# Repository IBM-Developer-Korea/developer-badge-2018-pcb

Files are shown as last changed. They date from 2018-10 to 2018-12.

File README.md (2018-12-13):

# Badge PCB

This repository contains schematic, PCB and BoM for Developer Day 2018 Badge

[KiCAD 5](http://kicad-pcb.org/download/) is used to design.

## 3D modeling

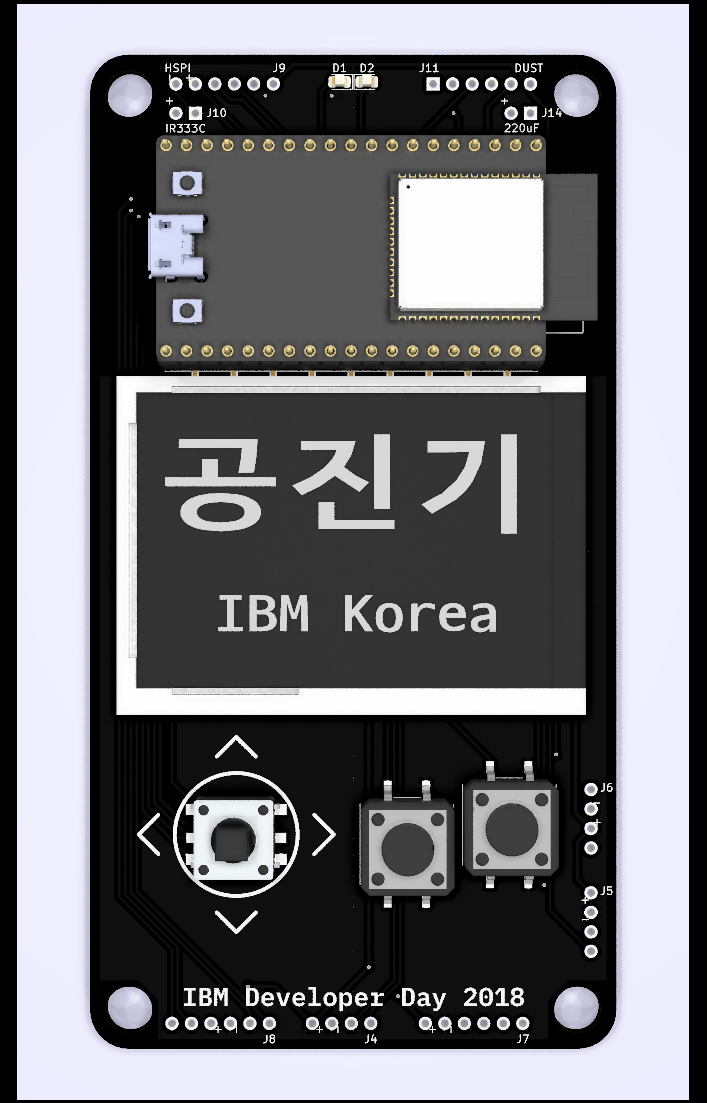
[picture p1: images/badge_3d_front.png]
Front

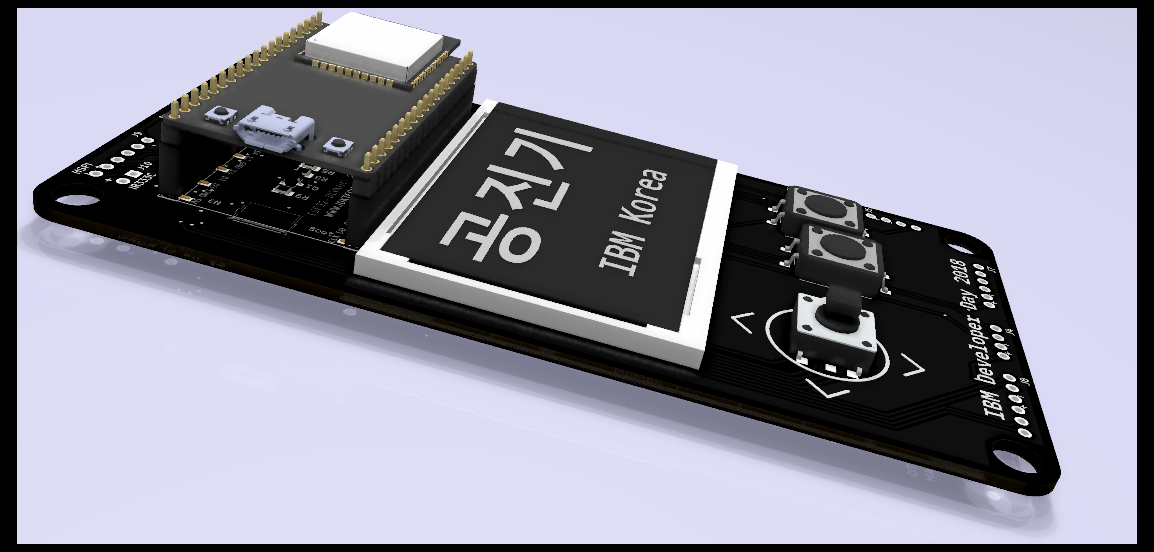
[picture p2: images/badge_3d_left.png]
Left

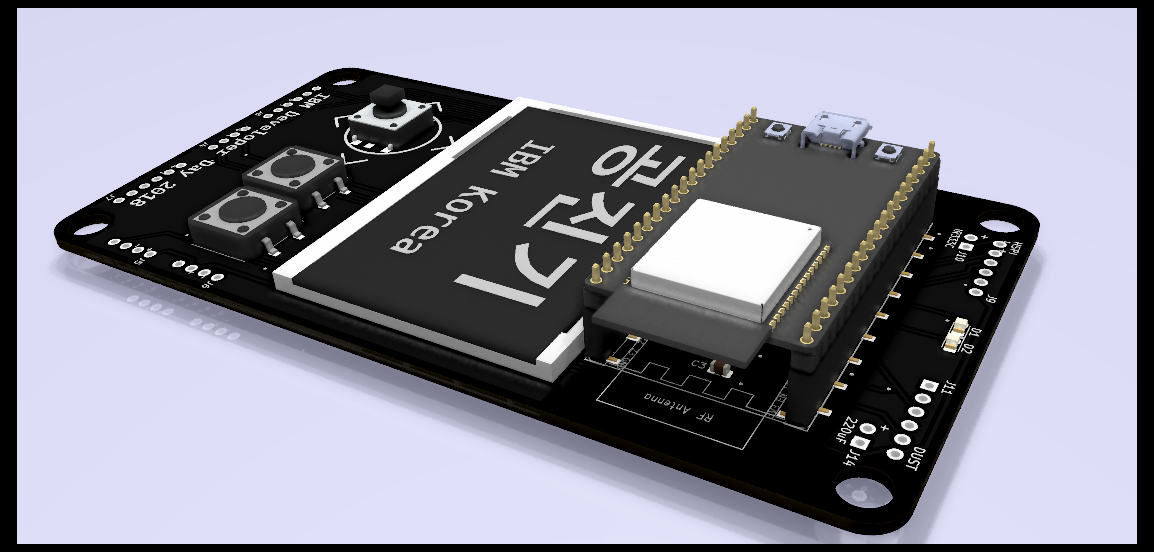
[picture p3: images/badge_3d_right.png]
Right

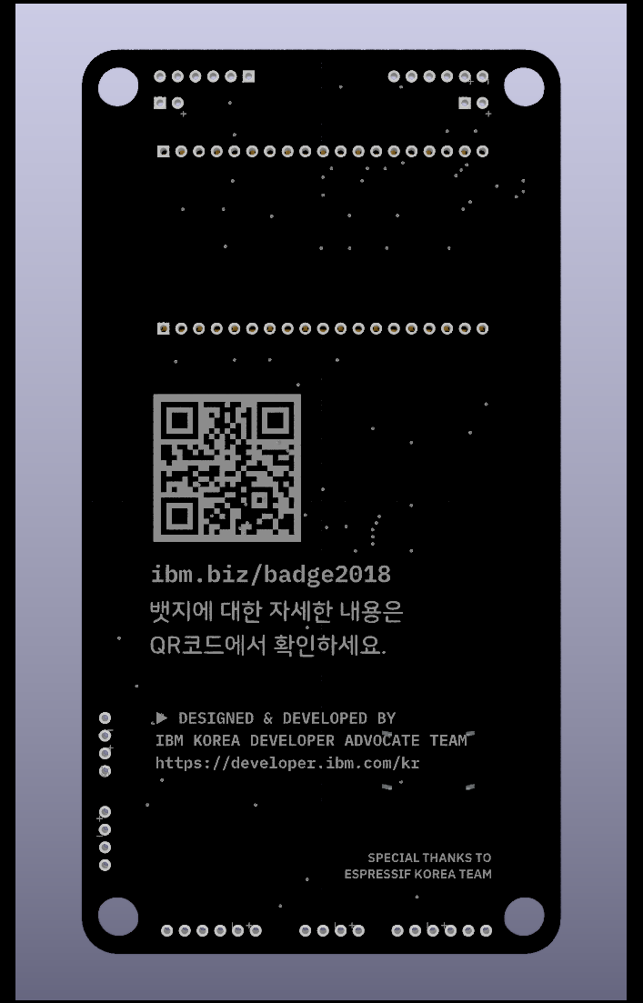
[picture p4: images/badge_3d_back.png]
Back


## Errata

* v1.0: in J9(HSPI), silk for +/- should be swapped. Correct pin is +(VCC), -(GND), GPIO14, GPIO12, GPIO13, GPIO15.

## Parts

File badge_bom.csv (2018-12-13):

Item | Qty | Reference(s) | Value | LibPart | Footprint | Datasheet | Field4 | Field5 | Field6 | Field7 | Field8
1 | 2 | C2, C8 | 2012/0.1uF | C_Small | C_0805
2 | 1 | C3 | 2012/100nF | C_Small | C_0805
3 | 1 | D1 | 2012/BLUE | LED_Small | LED_0805
4 | 1 | D2 | 2012/YELLOW | LED_Small | LED_0805
5 | 1 | DS1 | 18PIN LCD | LCD_SPI_18P | FFC-1x18-1MP_P0.80mm
6 | 1 | DS2 | 40PIN LCD | HT024SQV010NH | 05002HR-40C_1x40-1MP_P0.50mm_Horizontal
7 | 4 | H1, H2, H5, H6 | MountingHole | MountingHole | LanyardHole_6mm
8 | 1 | J1 | DevKitC_L | Conn_01x19_Female | PinSocket_1x19_P2.54mm_Vertical_BackOnly
9 | 1 | J2 | DevKitC_R | Conn_01x19_Female | PinSocket_1x19_P2.54mm_Vertical_BackOnly
10 | 1 | J4 | ADC_3 | Conn_01x04_Female | PinSocket_1x04_P2.54mm_Vertical
11 | 1 | J5 | ADC_2 | Conn_01x04_Female | PinSocket_1x04_P2.54mm_Vertical
12 | 1 | J6 | ADC_1 | Conn_01x04_Female | PinSocket_1x04_P2.54mm_Vertical
13 | 1 | J7 | DAC_1 | Conn_01x06_Female | PinSocket_1x06_P2.54mm_Vertical
14 | 1 | J8 | DAC_2 | Conn_01x06_Female | PinSocket_1x06_P2.54mm_Vertical
15 | 1 | J9 | HSPI | Conn_01x06_Female | PinSocket_1x06_P2.54mm_Vertical
16 | 1 | J10 | IR333C | Conn_01x02_Female | PinSocket_1x02_P2.54mm_Vertical
17 | 1 | J11 | DUST | Conn_01x06_Female | PinSocket_1x06_P2.54mm_Vertical
18 | 1 | J12 | DevKitC_L_SMD | Conn_01x19_Female | PinSocket_1x19_P2.54mm_Vertical_SMD_Pin1Right
19 | 1 | J13 | DevKitC_R_SMD | Conn_01x19_Female | PinSocket_1x19_P2.54mm_Vertical_SMD_Pin1Left
20 | 1 | J14 | 220uF | Conn_01x02_Female | PinSocket_1x02_P2.54mm_Vertical
21 | 1 | LCD1 | 2.4" LCD 18PIN | Housing | 2.4INCH_TFT_LCD_18P_0.80mm_FOLD
22 | 1 | LCD2 | 2.4" LCD 40PIN | Housing | 2.4INCH_TFT_LCD_40P_0.50mm_FOLD
23 | 1 | Q1 | SOT23/2N7002 | 2N7002 | SOT-23 | https://www.fairchildsemi.com/datasheets/2N/2N7002.pdf
24 | 3 | R4, R8, R9 | 2012/4.7R | R_Small | R_0805_2012Metric
25 | 2 | R5, R6 | 2012/1K | R_Small | R_0805_2012Metric
26 | 1 | R7 | 2012/220R | R_Small | R_0805_2012Metric
27 | 1 | SW3 | ITS-1103S | SW_Push | ITS-1103S |  | ILOSAM
28 | 1 | SW6 | ITS-1103S | SW_Push | ITS-1103S |  | ILOSAM
29 | 1 | SW7 | ITS_1500S_B | SW_5WAY | ITS-1500S-B |  | ILOSAM
30 | 1 | U1 | ESP32-DEVKITC-32D | ESP32-DEVKITC-32D | MODULE_ESP32-DEVKITC-32D-SILKONLY-SIMPLE | None | Espressif Systems | ESP32-DEVKITC-32D | None | Eval Board For Esp-Wroom-32 | Unavailable

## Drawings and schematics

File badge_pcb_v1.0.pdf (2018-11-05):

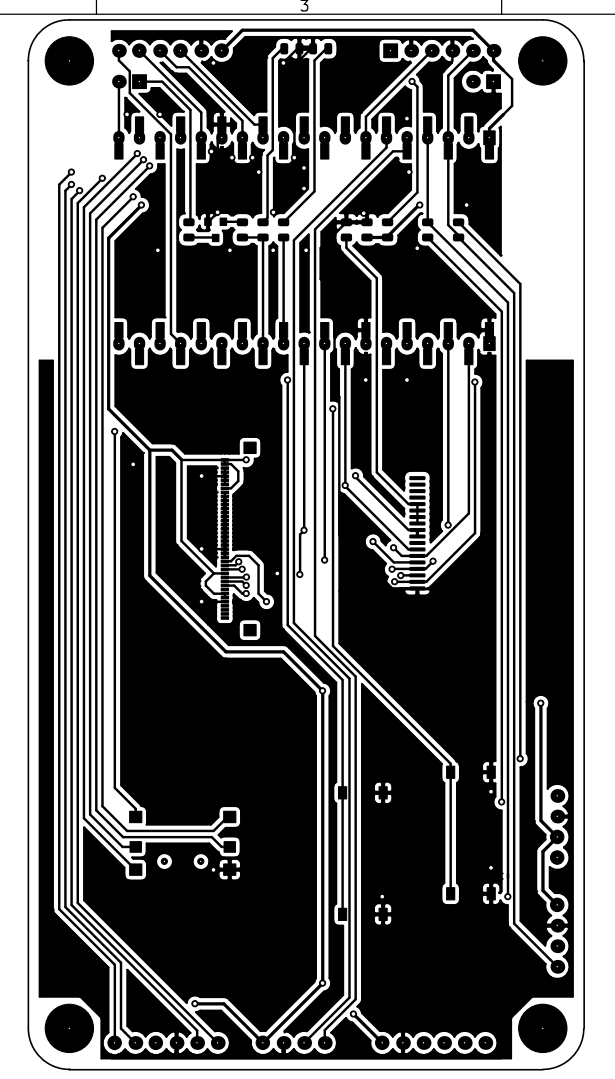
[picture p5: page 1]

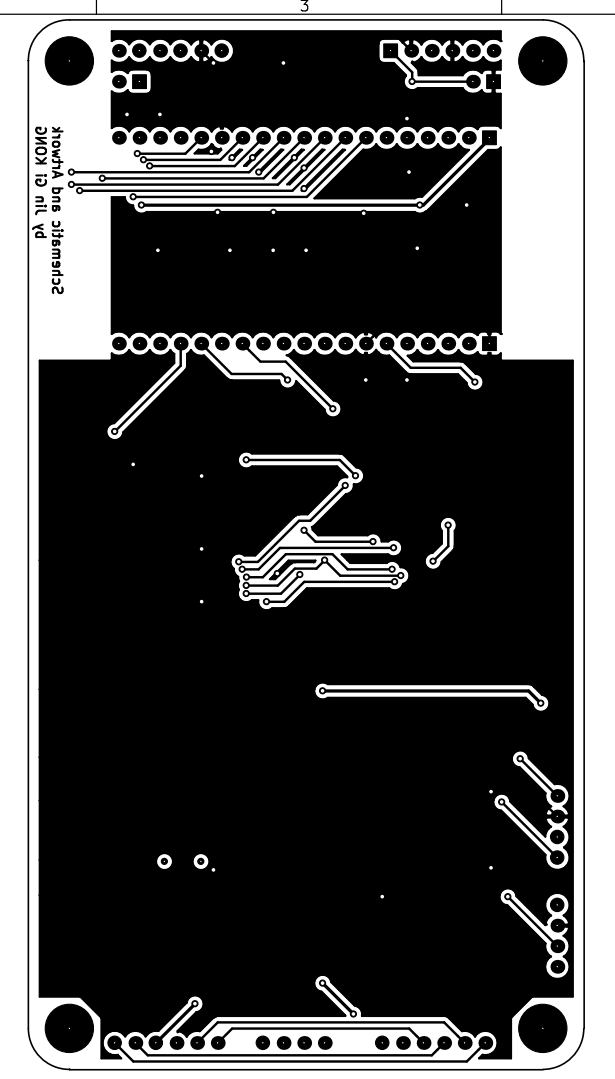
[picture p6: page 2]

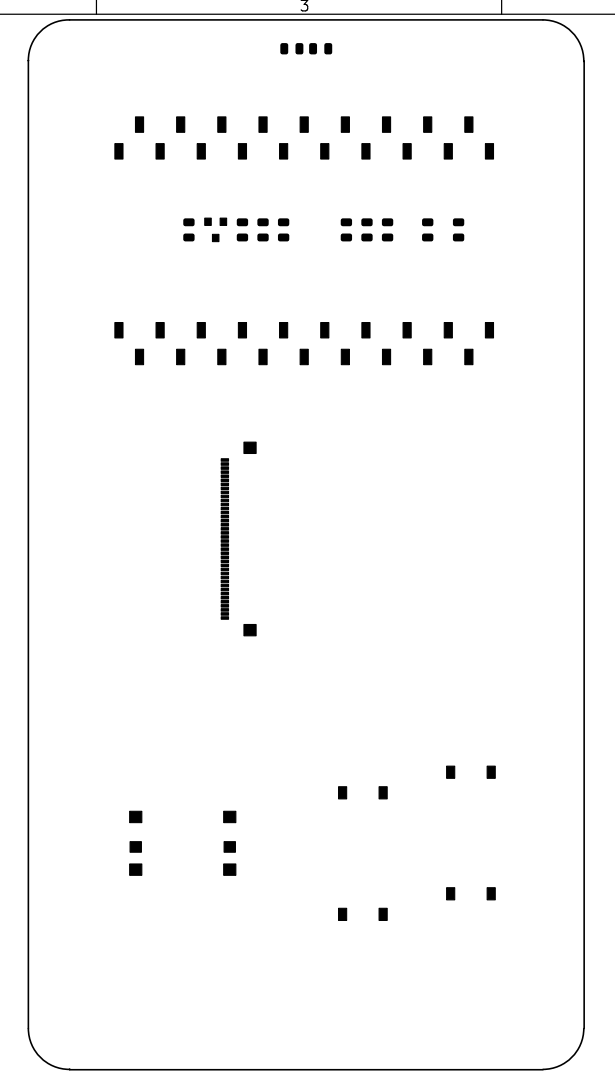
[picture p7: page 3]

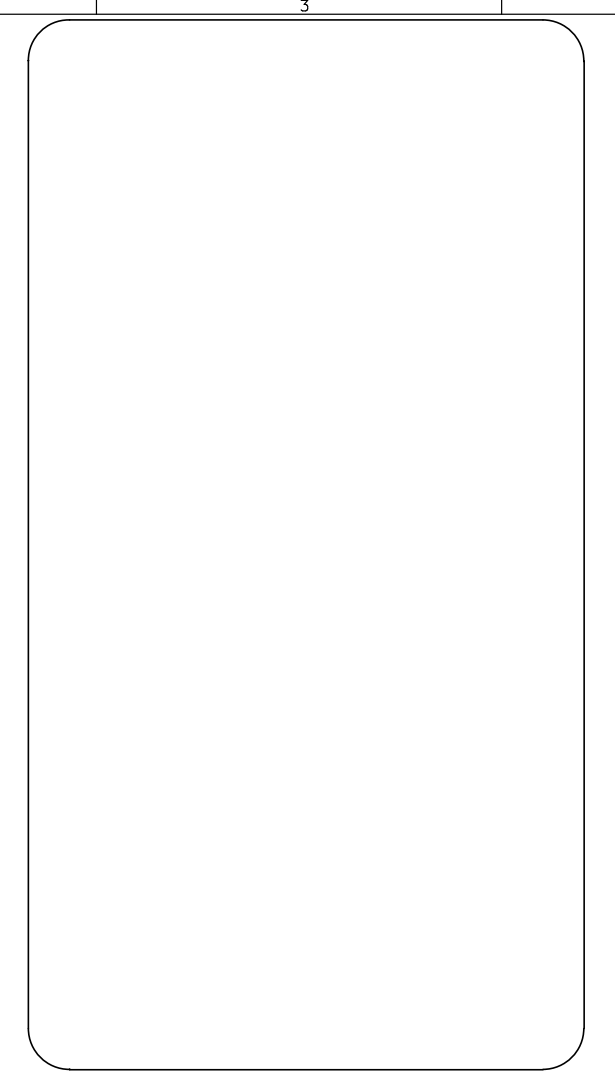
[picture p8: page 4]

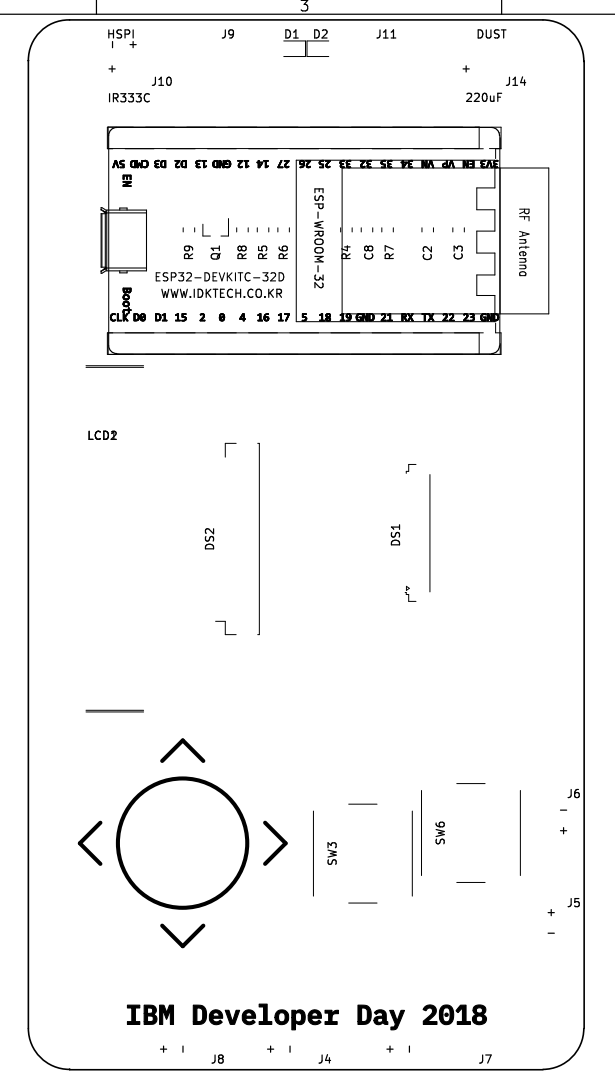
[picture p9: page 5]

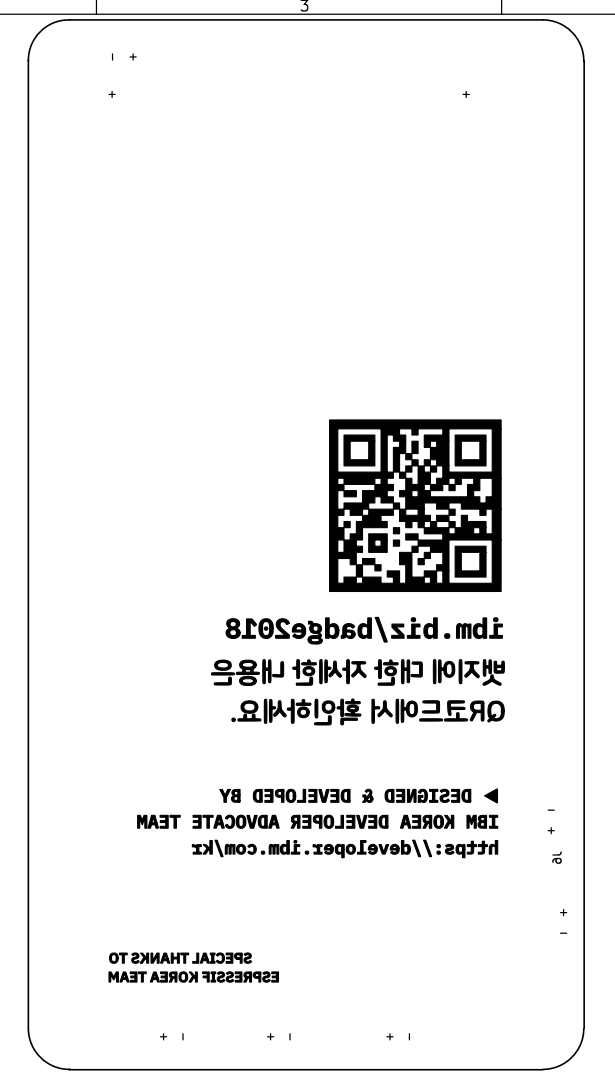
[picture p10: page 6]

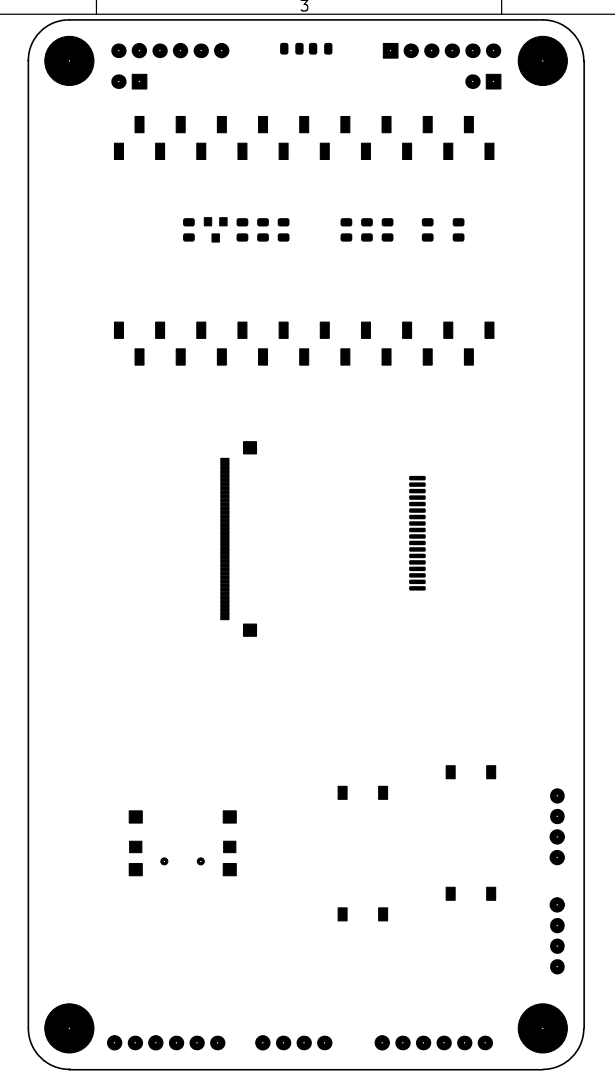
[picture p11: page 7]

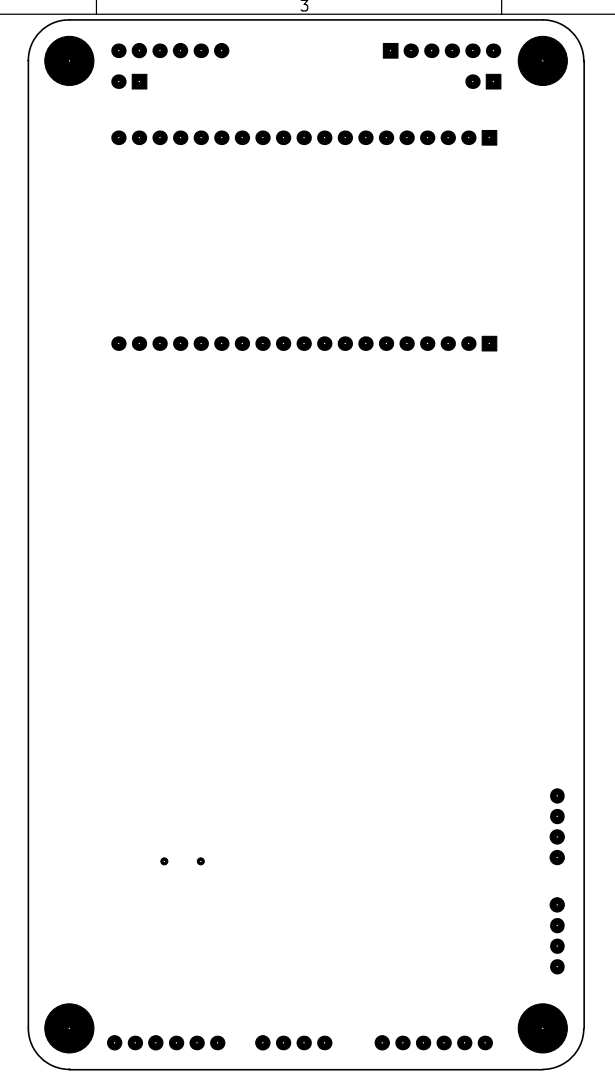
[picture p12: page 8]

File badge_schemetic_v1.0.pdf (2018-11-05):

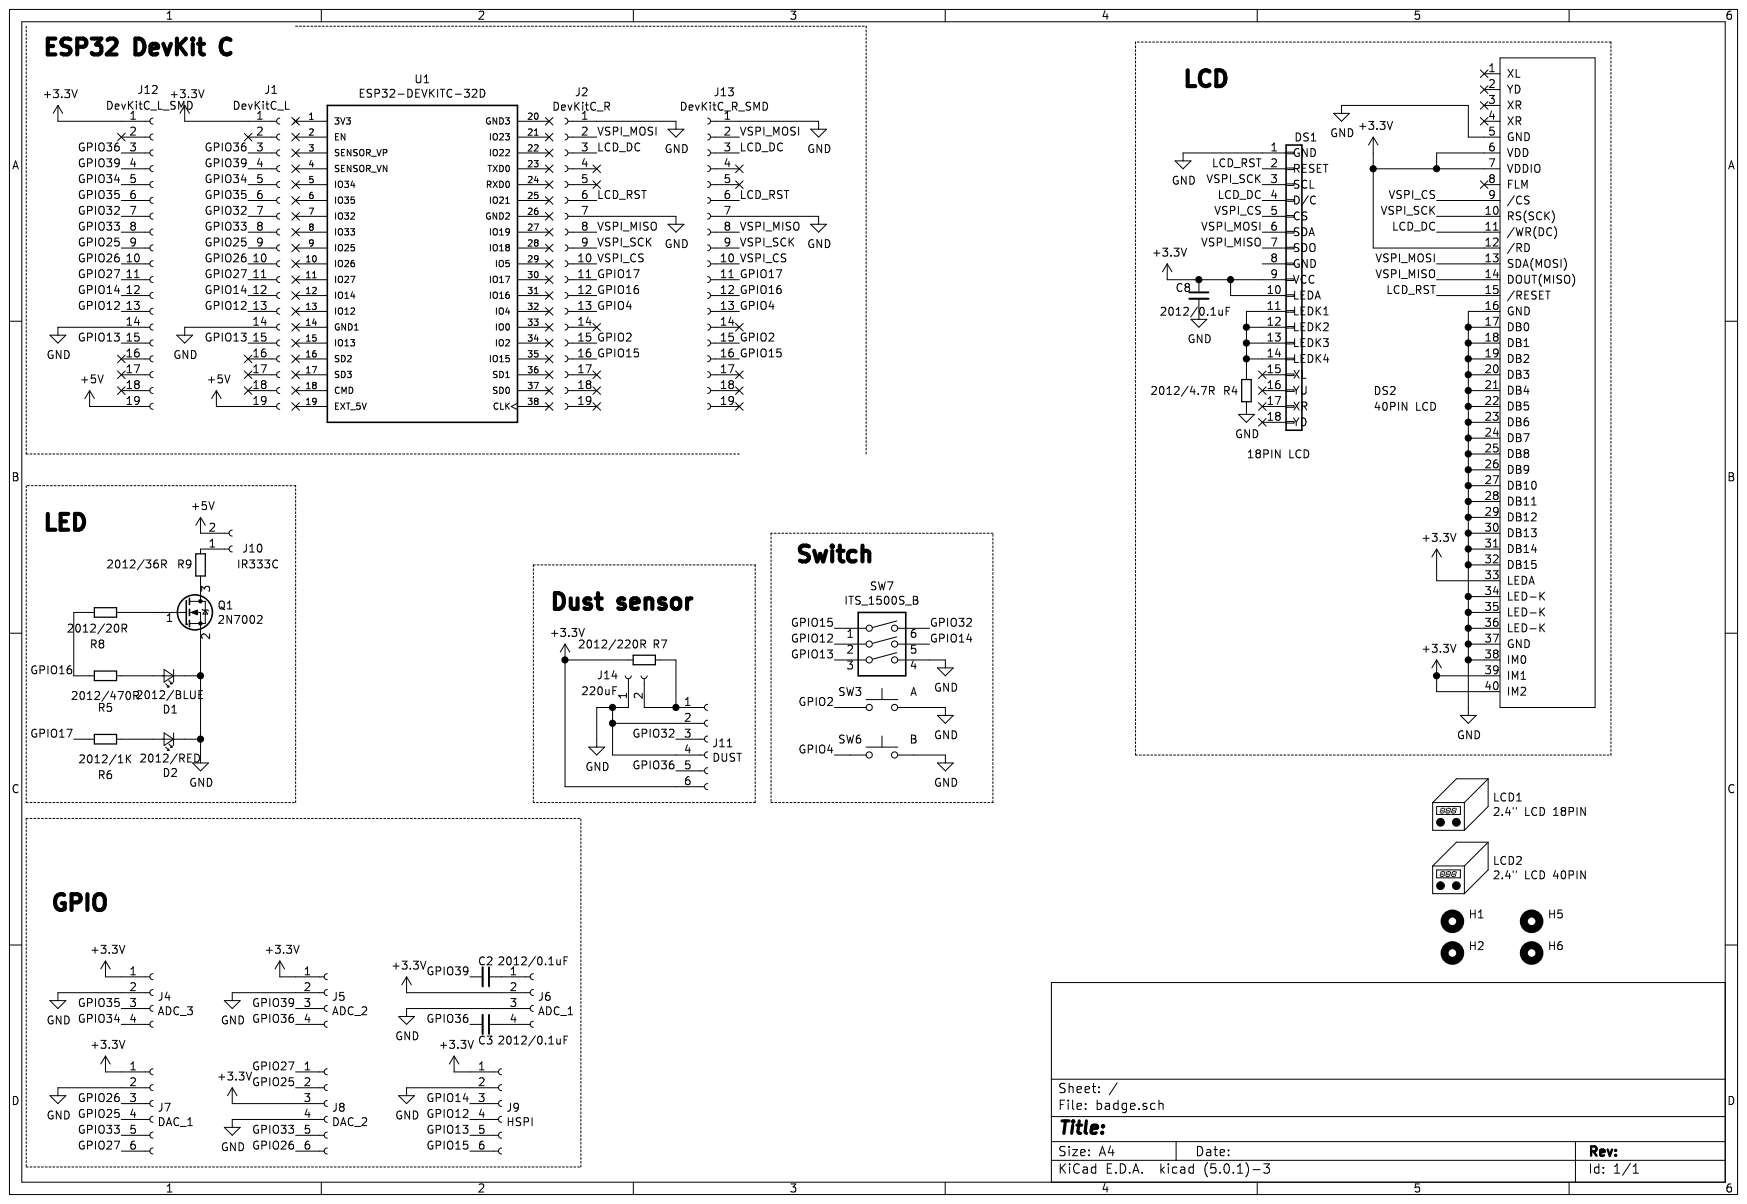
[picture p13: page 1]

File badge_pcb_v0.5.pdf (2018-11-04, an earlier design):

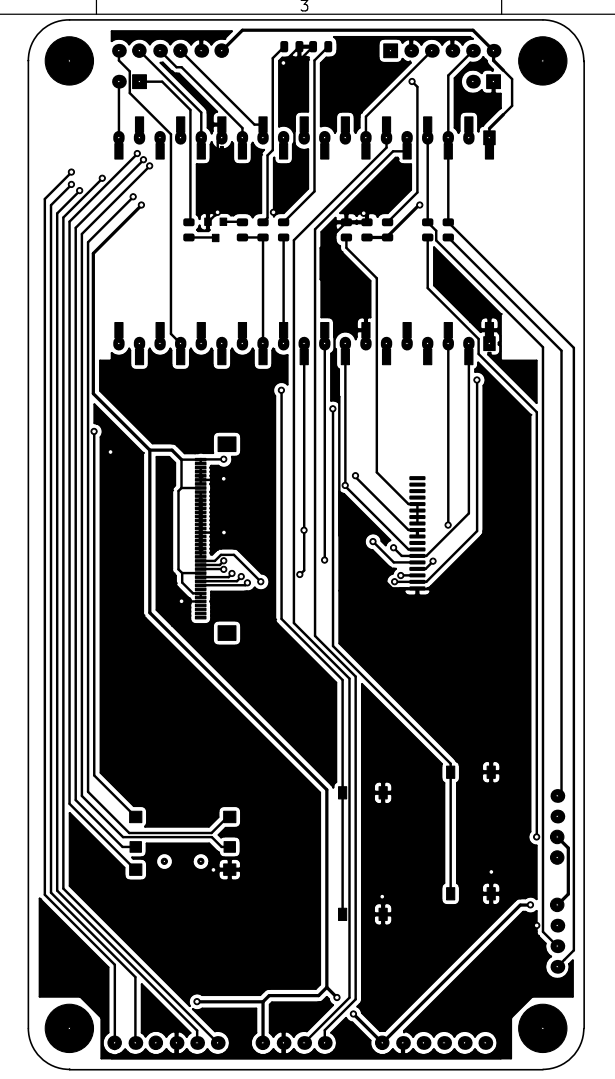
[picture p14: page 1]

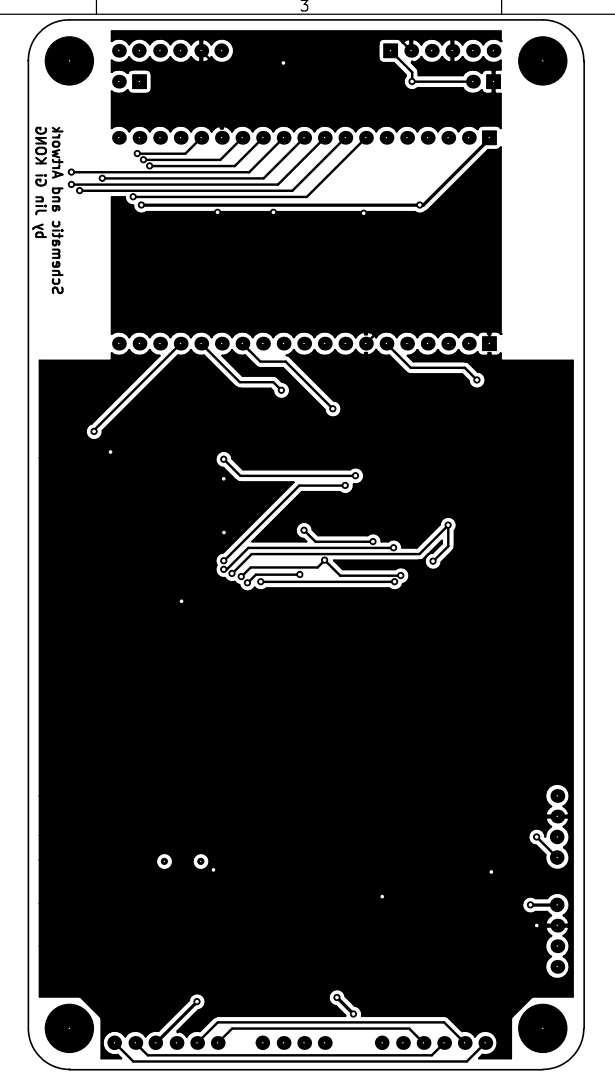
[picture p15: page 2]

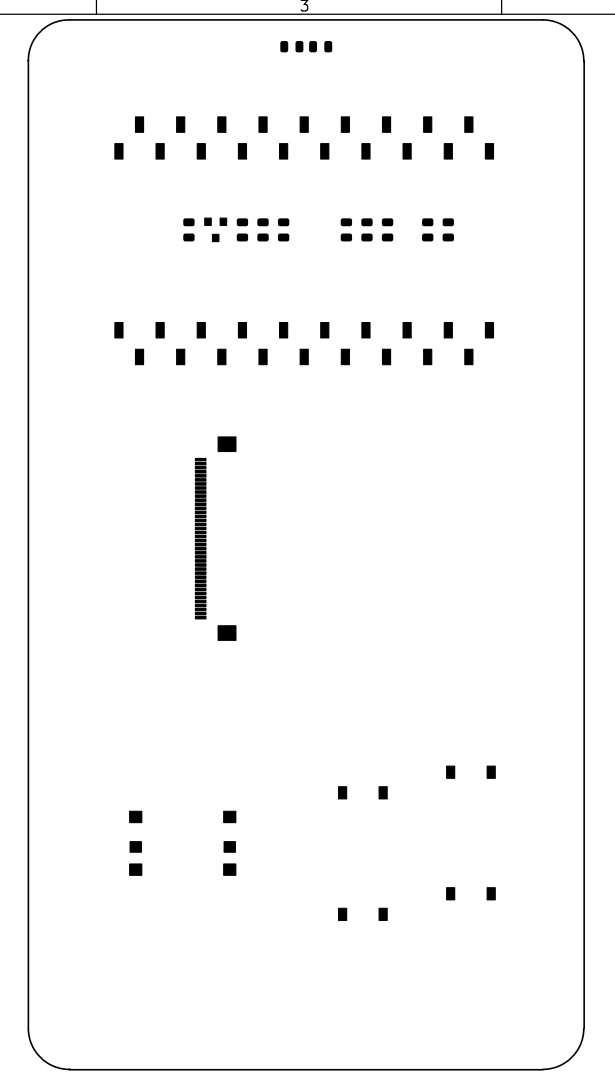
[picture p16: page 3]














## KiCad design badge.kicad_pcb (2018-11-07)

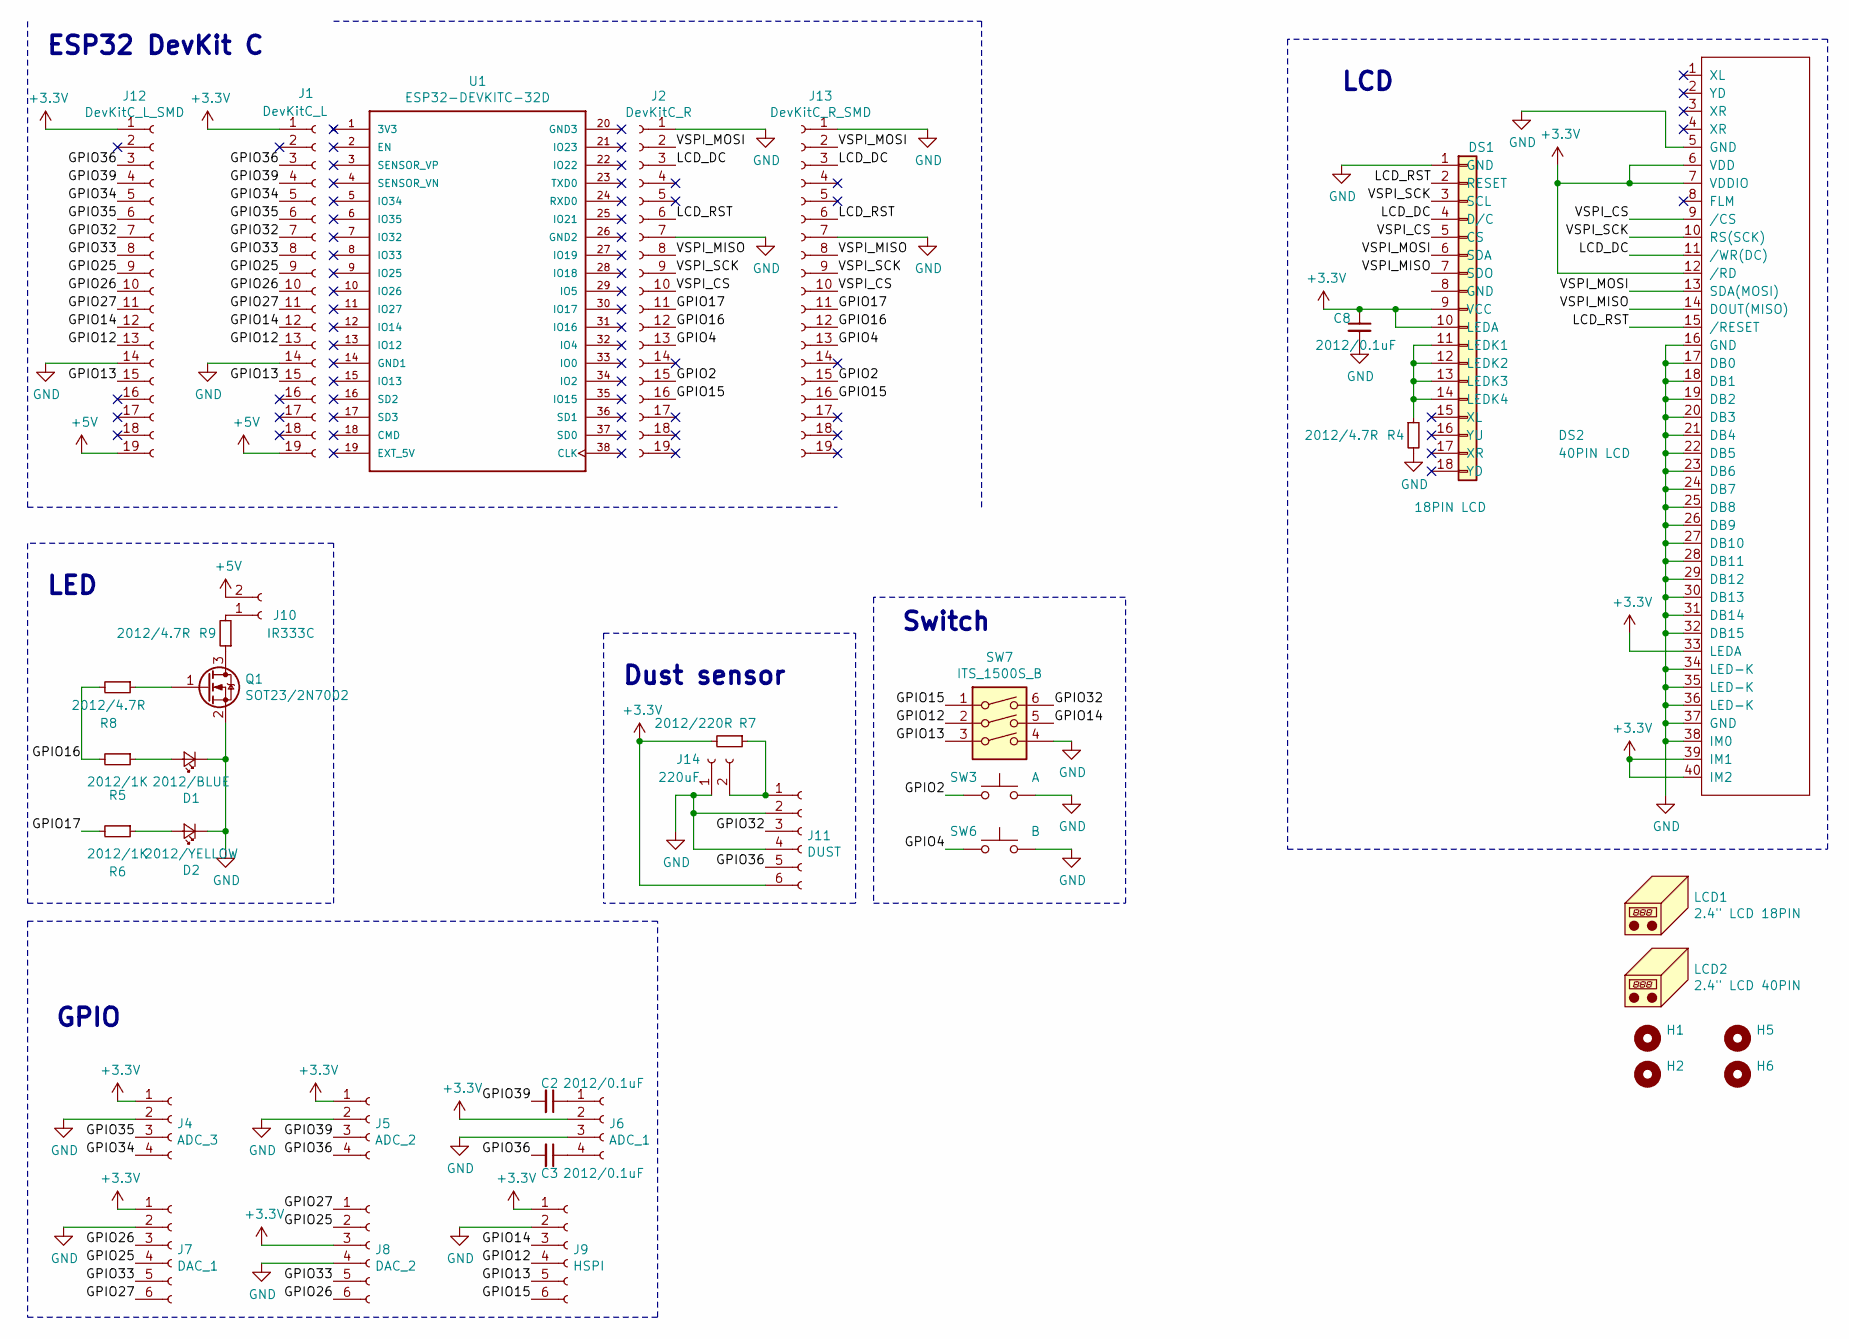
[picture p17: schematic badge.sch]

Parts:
C2, C3, C8: 2012/0.1uF; C_0805_2012Metric
D1: 2012/BLUE; LED_0805_2012Metric
D2: 2012/YELLOW; LED_0805_2012Metric
DS1: 18PIN LCD; COMMON_MOUNT_FFC-1x18-1MP_P0.80mm
DS2: 40PIN LCD; Yeonho_05002HR-40C_1x40-1MP_P0.50mm_Horizontal
H1, H2, H5, H6: MountingHole; LanyardHole_6mm
J1: DevKitC_L; PinSocket_1x19_P2.54mm_Vertical_Universal_Pin1Right
J2: DevKitC_R; PinSocket_1x19_P2.54mm_Vertical_BackOnly_NO3D
J4: ADC_3; PinSocket_1x04_P2.54mm_Vertical_NO3D_1S
J5: ADC_2; PinSocket_1x04_P2.54mm_Vertical_NO3D_1S
J6: ADC_1; PinSocket_1x04_P2.54mm_Vertical_NO3D_2S
J7: DAC_1; PinSocket_1x06_P2.54mm_Vertical_NO3D_1S
J8: DAC_2; PinSocket_1x06_P2.54mm_Vertical_NO3D_3S
J9: HSPI; PinSocket_1x06_P2.54mm_Vertical_NO3D_5S
J10: IR333C; PinSocket_1x02_P2.54mm_Vertical_NO3D
J11: DUST; PinSocket_1x06_P2.54mm_Vertical_NO3D
J12: DevKitC_L_SMD; PinSocket_1x19_P2.54mm_Vertical_SMD_Pin1Right
J13: DevKitC_R_SMD; PinSocket_1x19_P2.54mm_Vertical_SMD_Pin1Left
J14: 220uF; PinSocket_1x02_P2.54mm_Vertical_NO3D
LCD1: 2.4\" LCD 18PIN; 2.4INCH_TFT_LCD_18P_0.80mm_FOLD_JGKONG
LCD2: 2.4\" LCD 40PIN; 2.4INCH_TFT_LCD_40P_0.50mm_FOLD
Q1: SOT23/2N7002; SOT-23
R4, R8, R9: 2012/4.7R; R_0805_2012Metric
R5, R6: 2012/1K; R_0805_2012Metric
R7: 2012/220R; R_0805_2012Metric
SW3: A; ITS-1103S
SW6: B; ITS-1103S
SW7: ITS_1500S_B; ITS-1500S-B-SILKDIR
U1: ESP32-DEVKITC-32D; MODULE_ESP32-DEVKITC-32D-SILKONLY-SIMPLE

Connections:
+3V3: C8.1, DS1.9 (VCC), DS1.10 (LEDA), DS2.6 (VDD), DS2.7 (VDDIO), DS2.12 (/RD), DS2.33 (LEDA), DS2.39 (IM1), DS2.40 (IM2), J1.1, J4.1, J5.1, J6.2, J7.1, J8.3, J9.1, J11.6, J12.1, R7.2
+5V: J1.19, J10.2, J12.19
/GPIO2: J2.15, J13.15, SW3.1
/GPIO4: J2.13, J13.13, SW6.1
/GPIO12: J1.13, J9.4, J12.13, SW7.2
/GPIO13: J1.15, J9.5, J12.15, SW7.3
/GPIO14: J1.12, J9.3, J12.12, SW7.5
/GPIO15: J2.16, J9.6, J13.16, SW7.1
/GPIO16: J2.12, J13.12, R5.2, R8.2
/GPIO17: J2.11, J13.11, R6.2
/GPIO25: J1.9, J7.4, J8.2, J12.9
/GPIO26: J1.10, J7.3, J8.6, J12.10
/GPIO27: J1.11, J7.6, J8.1, J12.11
/GPIO32: J1.7, J11.3, J12.7, SW7.6
/GPIO33: J1.8, J7.5, J8.5, J12.8
/GPIO34: J1.5, J4.4, J12.5
/GPIO35: J1.6, J4.3, J12.6
/GPIO36: C3.2, J1.3, J5.4, J11.5, J12.3
/GPIO39: C2.2, J1.4, J5.3, J12.4
/LCD_DC: DS1.4 (D/C), DS2.11 (/WR(DC)), J2.3, J13.3
/LCD_RST: DS1.2 (RESET), DS2.15 (/RESET), J2.6, J13.6
/VSPI_CS: DS1.5 (CS), DS2.9 (/CS), J2.10, J13.10
/VSPI_MISO: DS1.7 (SDO), DS2.14 (DOUT(MISO)), J2.8, J13.8
/VSPI_MOSI: DS1.6 (SDA), DS2.13 (SDA(MOSI)), J2.2, J13.2
/VSPI_SCK: DS1.3 (SCL), DS2.10 (RS(SCK)), J2.9, J13.9
GND: C8.2, D1.1 (K), D2.1 (K), DS1.1 (GND), DS2.5 (GND), DS2.16 (GND), DS2.17 (DB0), DS2.18 (DB1), DS2.19 (DB2), DS2.20 (DB3), DS2.21 (DB4), DS2.22 (DB5), DS2.23 (DB6), DS2.24 (DB7), DS2.25 (DB8), DS2.26 (DB9), DS2.27 (DB10), DS2.28 (DB11), DS2.29 (DB12), DS2.30 (DB13), DS2.31 (DB14), DS2.32 (DB15), DS2.34 (LED-K), DS2.35 (LED-K), DS2.36 (LED-K), DS2.37 (GND), DS2.38 (IM0), J1.14, J2.1, J2.7, J4.2, J5.2, J6.3, J7.2, J8.4, J9.2, J11.2, J11.4, J12.14, J13.1, J13.7, J14.1, Q1.2 (S), R4.2, SW3.2, SW6.2, SW7.4
unnamed: C2.1, J6.1
unnamed: C3.1, J6.4
unnamed: D1.2 (A), R5.1
unnamed: D2.2 (A), R6.1
unnamed: DS1.11 (LEDK1), DS1.12 (LEDK2), DS1.13 (LEDK3), DS1.14 (LEDK4), R4.1
unnamed: J10.1, R9.2
unnamed: J11.1, J14.2, R7.1
unnamed: Q1.1 (G), R8.1
unnamed: Q1.3 (D), R9.1

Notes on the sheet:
LCD
ESP32 DevKit C
GPIO
Switch
LED
Dust sensor

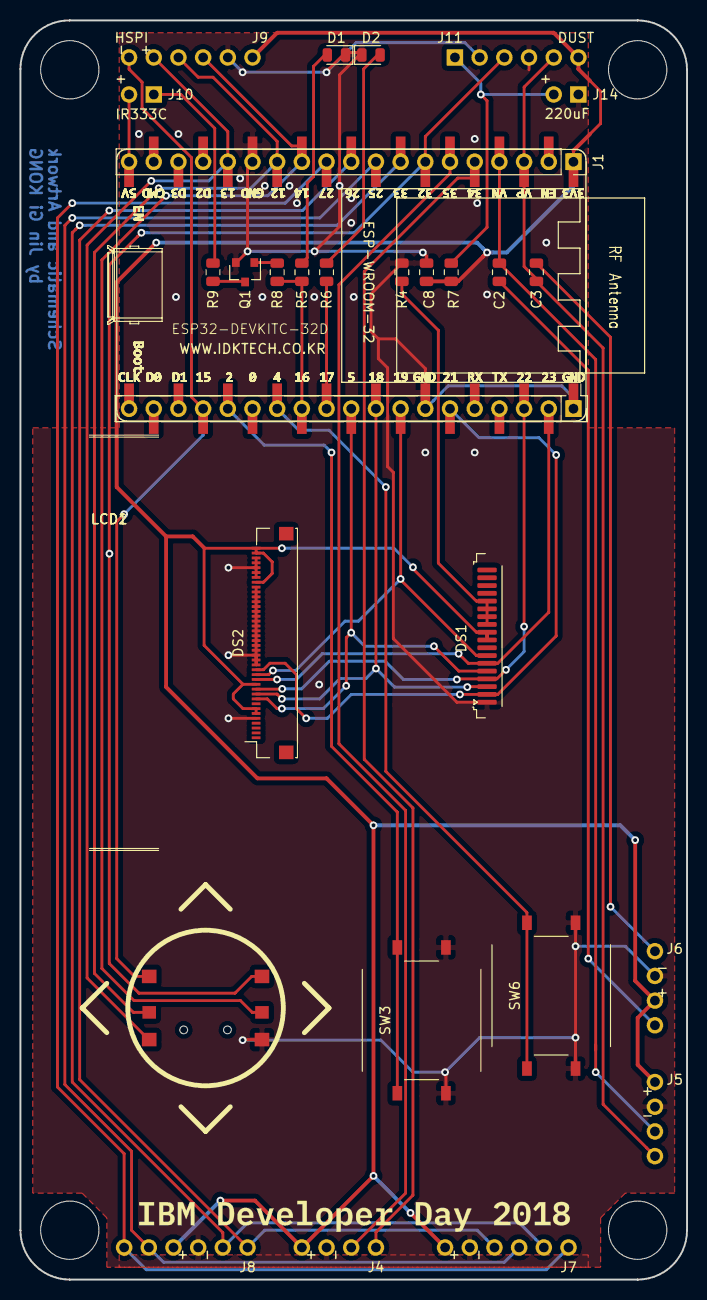
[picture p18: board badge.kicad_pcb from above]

Board: 2 copper layers, 68.6 x 129.5 mm, 36 parts (0 on the bottom side), 35 nets.

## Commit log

2018-10-28 Add btn, jumpers
    [badge.kicad_pcb, badge.sch]
2018-10-29 Change to manual PCB
    [badge.kicad_pcb, badge.sch]
2018-10-29 Square layout
    [badge-B.Cu.gbr, badge-B.Mask.gbr, badge-B.Paste.gbr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]
2018-10-29 Arranged to v0.1
    [badge-B.Cu.gbr, badge-B.Mask.gbr, badge-B.Paste.gbr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]
2018-10-30 v0.2 add dust sensor and 5 way tact switch
    * LED direction corrected
    * Pin adjusted
    [badge-B.Cu.gbr, badge-B.Mask.gbr, badge-B.Paste.gbr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]
2018-10-31 v0.3 0.3mm track, SMT/THT pinsocket support
    [badge-B.Cu.gbr, badge-B.Mask.gbr, badge-B.Paste.gbr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]
2018-10-31 Vertical badge style
    * Change C9 footprint to 2816
    * Add 3D model for 5 wat tactile switch
    * 3D models should be located in ${HOME}/kicad/template
    [badge.kicad_pcb, badge.sch]
2018-11-02 Modify footprints for Silk, add IR333C
    [badge.kicad_pcb, badge.sch]
2018-11-02 Change button
    [badge.kicad_pcb]
2018-11-03 Update v0.4, vertical long before tracks
    * Move footprint library to DeveloperDay2018Badge
    * Add symbol library, 3D models into project
    * Change board color
    * Increase R, C, LED size to 0805(2012)
    * Remove front solder mask for ESP32 DevKitC socket header, to make clean SMD socket pad.
    * Add silk for ESP32 DevKitC
    * Add silk direction in footprint for ITS-1550S-B 5 way tact switch
    * Add footprint and 3D for ITS-1106 tact switch
    * Change ESP32 DevKitC 3D model from SnapEDA
    * Remove THT 19pin socket 3D for ESP32 DevKitC
    [badge.kicad_pcb, badge.sch]
2018-11-04 Rout'ing
    * Add dummy pad for ESP32 DevKitC footprint to avoid errors
    * Add silk guide for LCD attachment
    * Add alternative 40pin LCD connector
    * Add logo and information in silk layer
    [badge-B.Cu.gbr, badge-B.Mask.gbr, badge-B.Paste.gbr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]
2018-11-04 v0.5 Finish tracks, final review
    * Remove paste at 18pin LCD
    [badge-B.Cu.gbr, badge-B.Mask.gbr, badge-B.Paste.gbr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]
2018-11-05 v1.0 release
    * Update 40pin footprint
    * Update tracks
    [badge-B.Cu.gbr, badge-B.Mask.gbr, badge-B.Paste.gbr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]
2018-11-07 Fix 3D model path into project
    * Change R values
    * Fix a few tracks
    [Tactal Switch - SMD (12mmx12mmx4.3mm).stp, badge.csv, badge.kicad_pcb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]
2018-11-29 Remove 3D models
    [Tactal Switch - SMD (12mmx12mmx4.3mm).stp, open-smart 2.4 tft.step, open-smart 2.4 tft_with_name.step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]
2018-12-13 Add badge BoM
    [badge.csv, badge_bom.csv]
